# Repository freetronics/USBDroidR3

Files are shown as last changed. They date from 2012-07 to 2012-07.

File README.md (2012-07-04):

Freetronics USBDroid R3
=======================
Copyright 2011-2012 Freetronics Pty Ltd  
Freetronics site:  www.freetronics.com  
Freetronics email: info@freetronics.com  

The USBDroid is a 100% Arduino Compatible Board, based on the existing
Uno, but with improvements and updates for ease of use, cost
and getting started. It also includes on-board USB host functionality
using a dedicated port.

Features:

 * Micro-USB connector
 * Integrated USB host functionality on a dedicated USB connector
 * Overlay guide where you need it (both top and bottom)
 * D13 pin works for everything
 * RX pin biased
 * Mounting holes, power and X3 pads
 * All connections in the same place

You can view more at our product page at:

  http://www.freetronics.com/usbdroid

The "docs" folder within this repository includes a handy copy of the
schematic in PDF format, images of the pcb, and our Getting Started
guide that ships with each board.

INSTALLATION
------------
The design is saved as an EAGLE project. EAGLE PCB design software is
available from www.cadsoftusa.com free for non-commercial use. To use
this project download it and place the directory containing these files
into the "eagle" directory on your computer. Then open EAGLE and
navigate to Projects -> eagle -> USBHost.

DISTRIBUTION
------------
The specific terms of distribution of this project are governed by the
license referenced below.

LICENSE
-------
This work is licensed under the
Creative Commons Attribution-Share Alike License.  
To view a copy of this license, visit

  http://creativecommons.org/licenses/by-sa/3.0/  
  http://creativecommons.org/licenses/by-sa/3.0/legalcode

or send a letter to

  Creative Commons  
  171 Second Street, Suite 300  
  San Francisco  
  California, 94105  
  USA

The "license" folder within this repository also contains copies of the
licences referenced above.

CREDITS
-------
The USBHost was designed by Marc Alexander (marc@freetronics.com).

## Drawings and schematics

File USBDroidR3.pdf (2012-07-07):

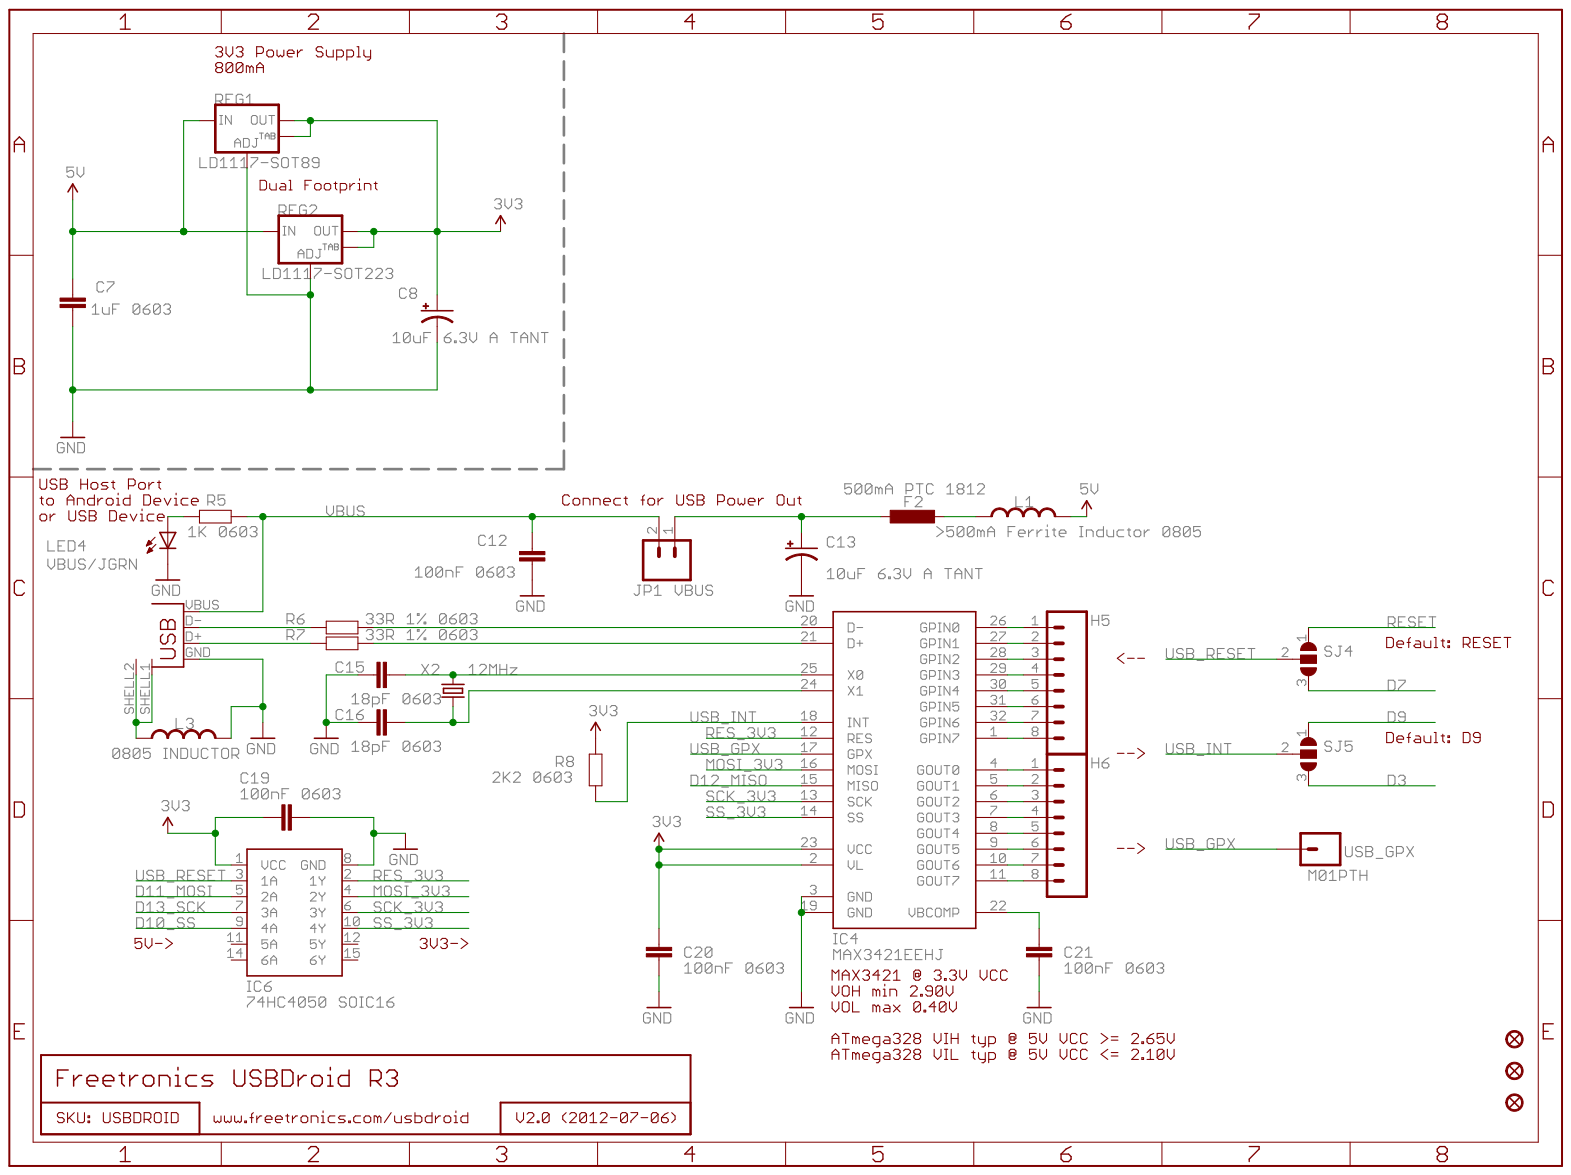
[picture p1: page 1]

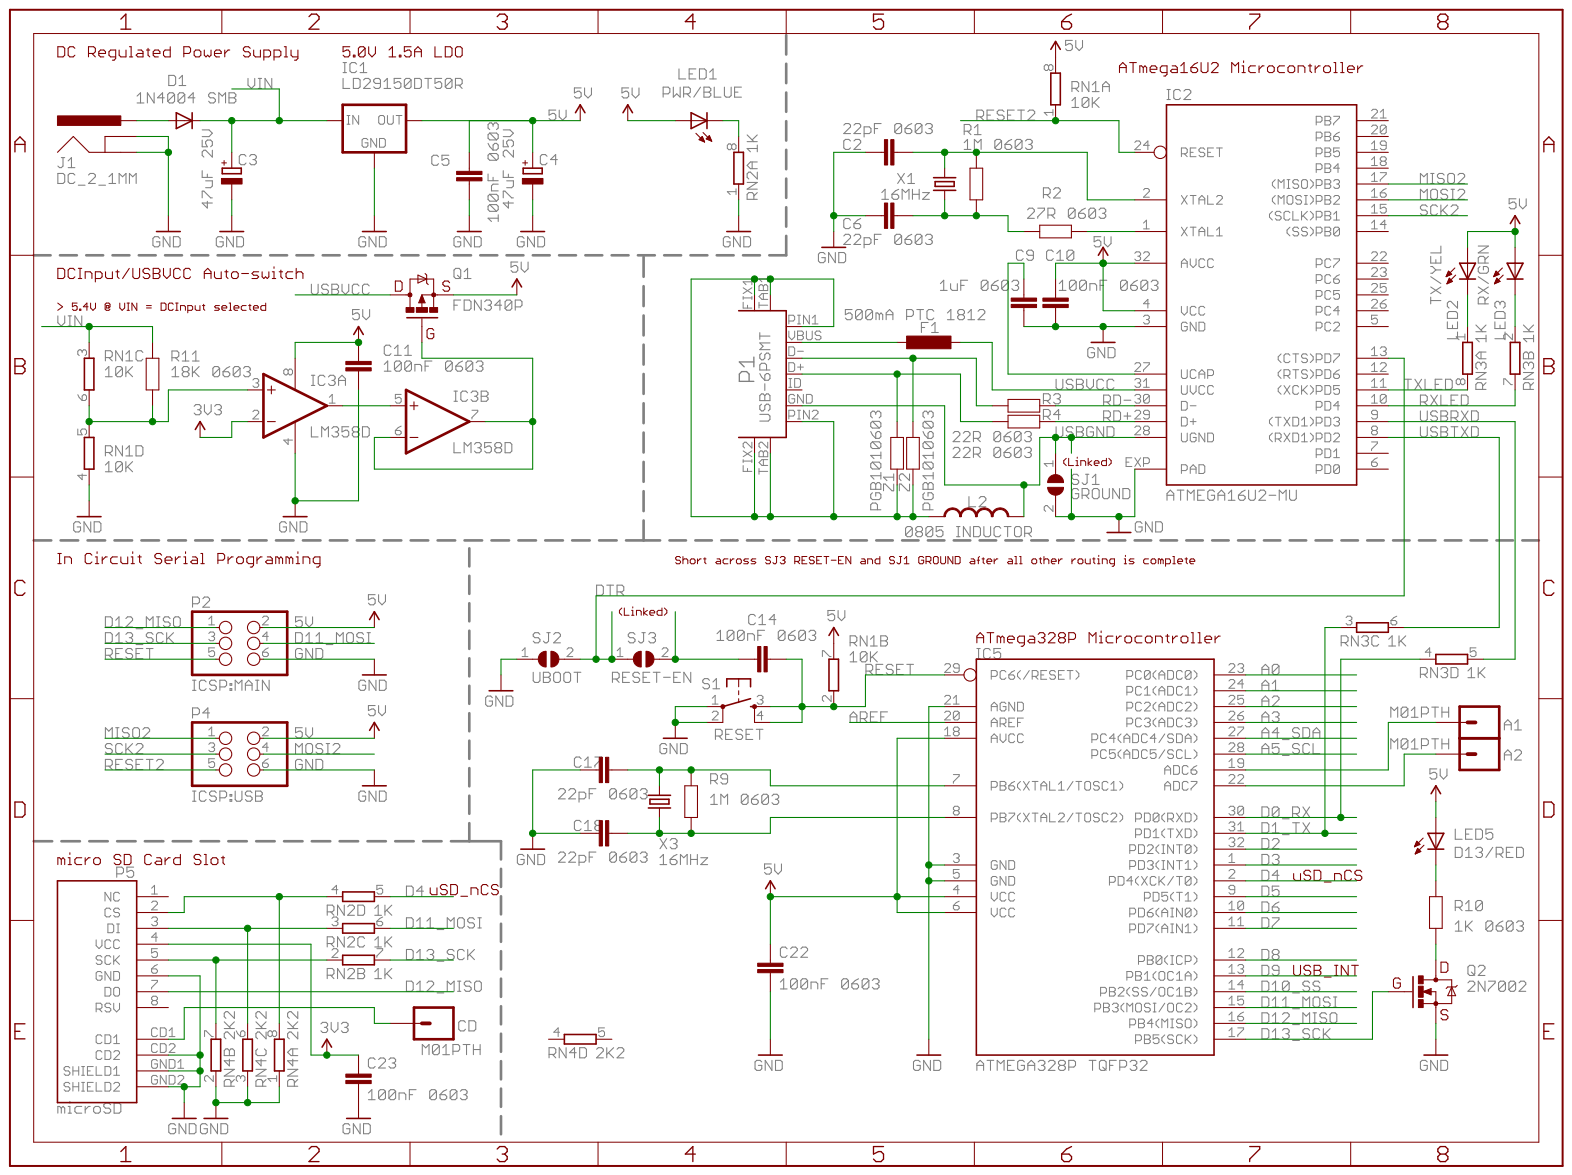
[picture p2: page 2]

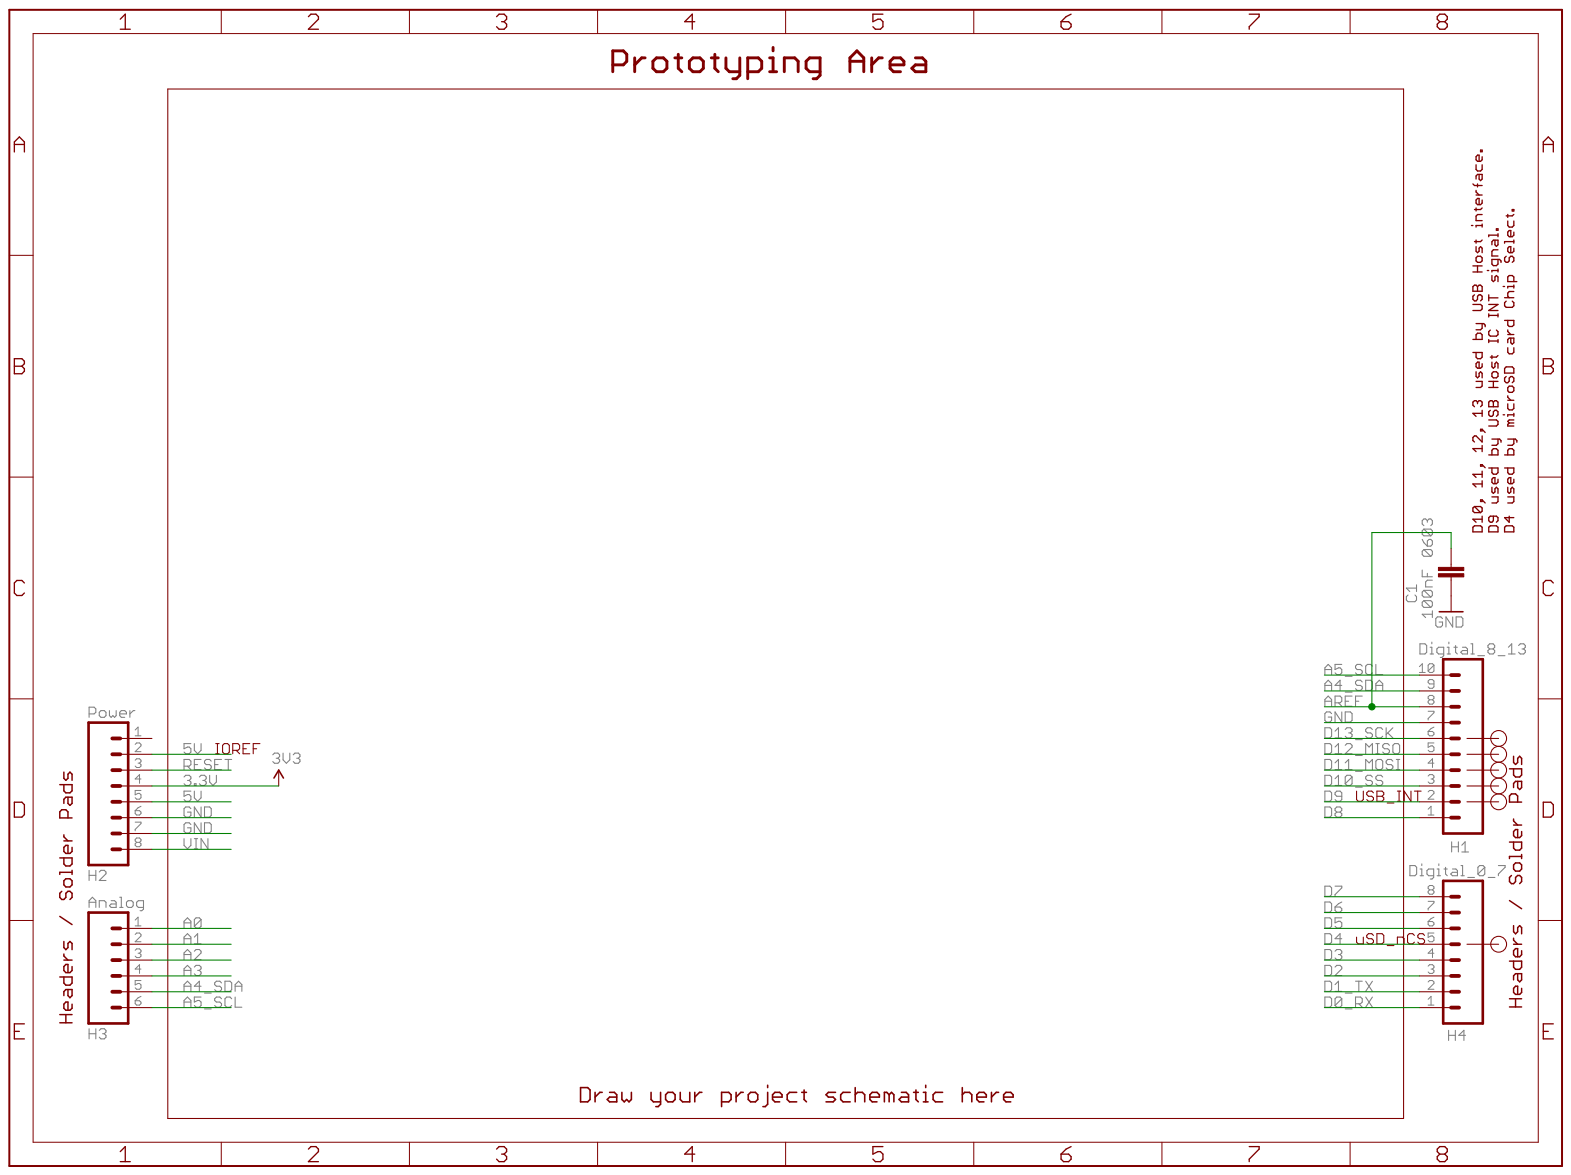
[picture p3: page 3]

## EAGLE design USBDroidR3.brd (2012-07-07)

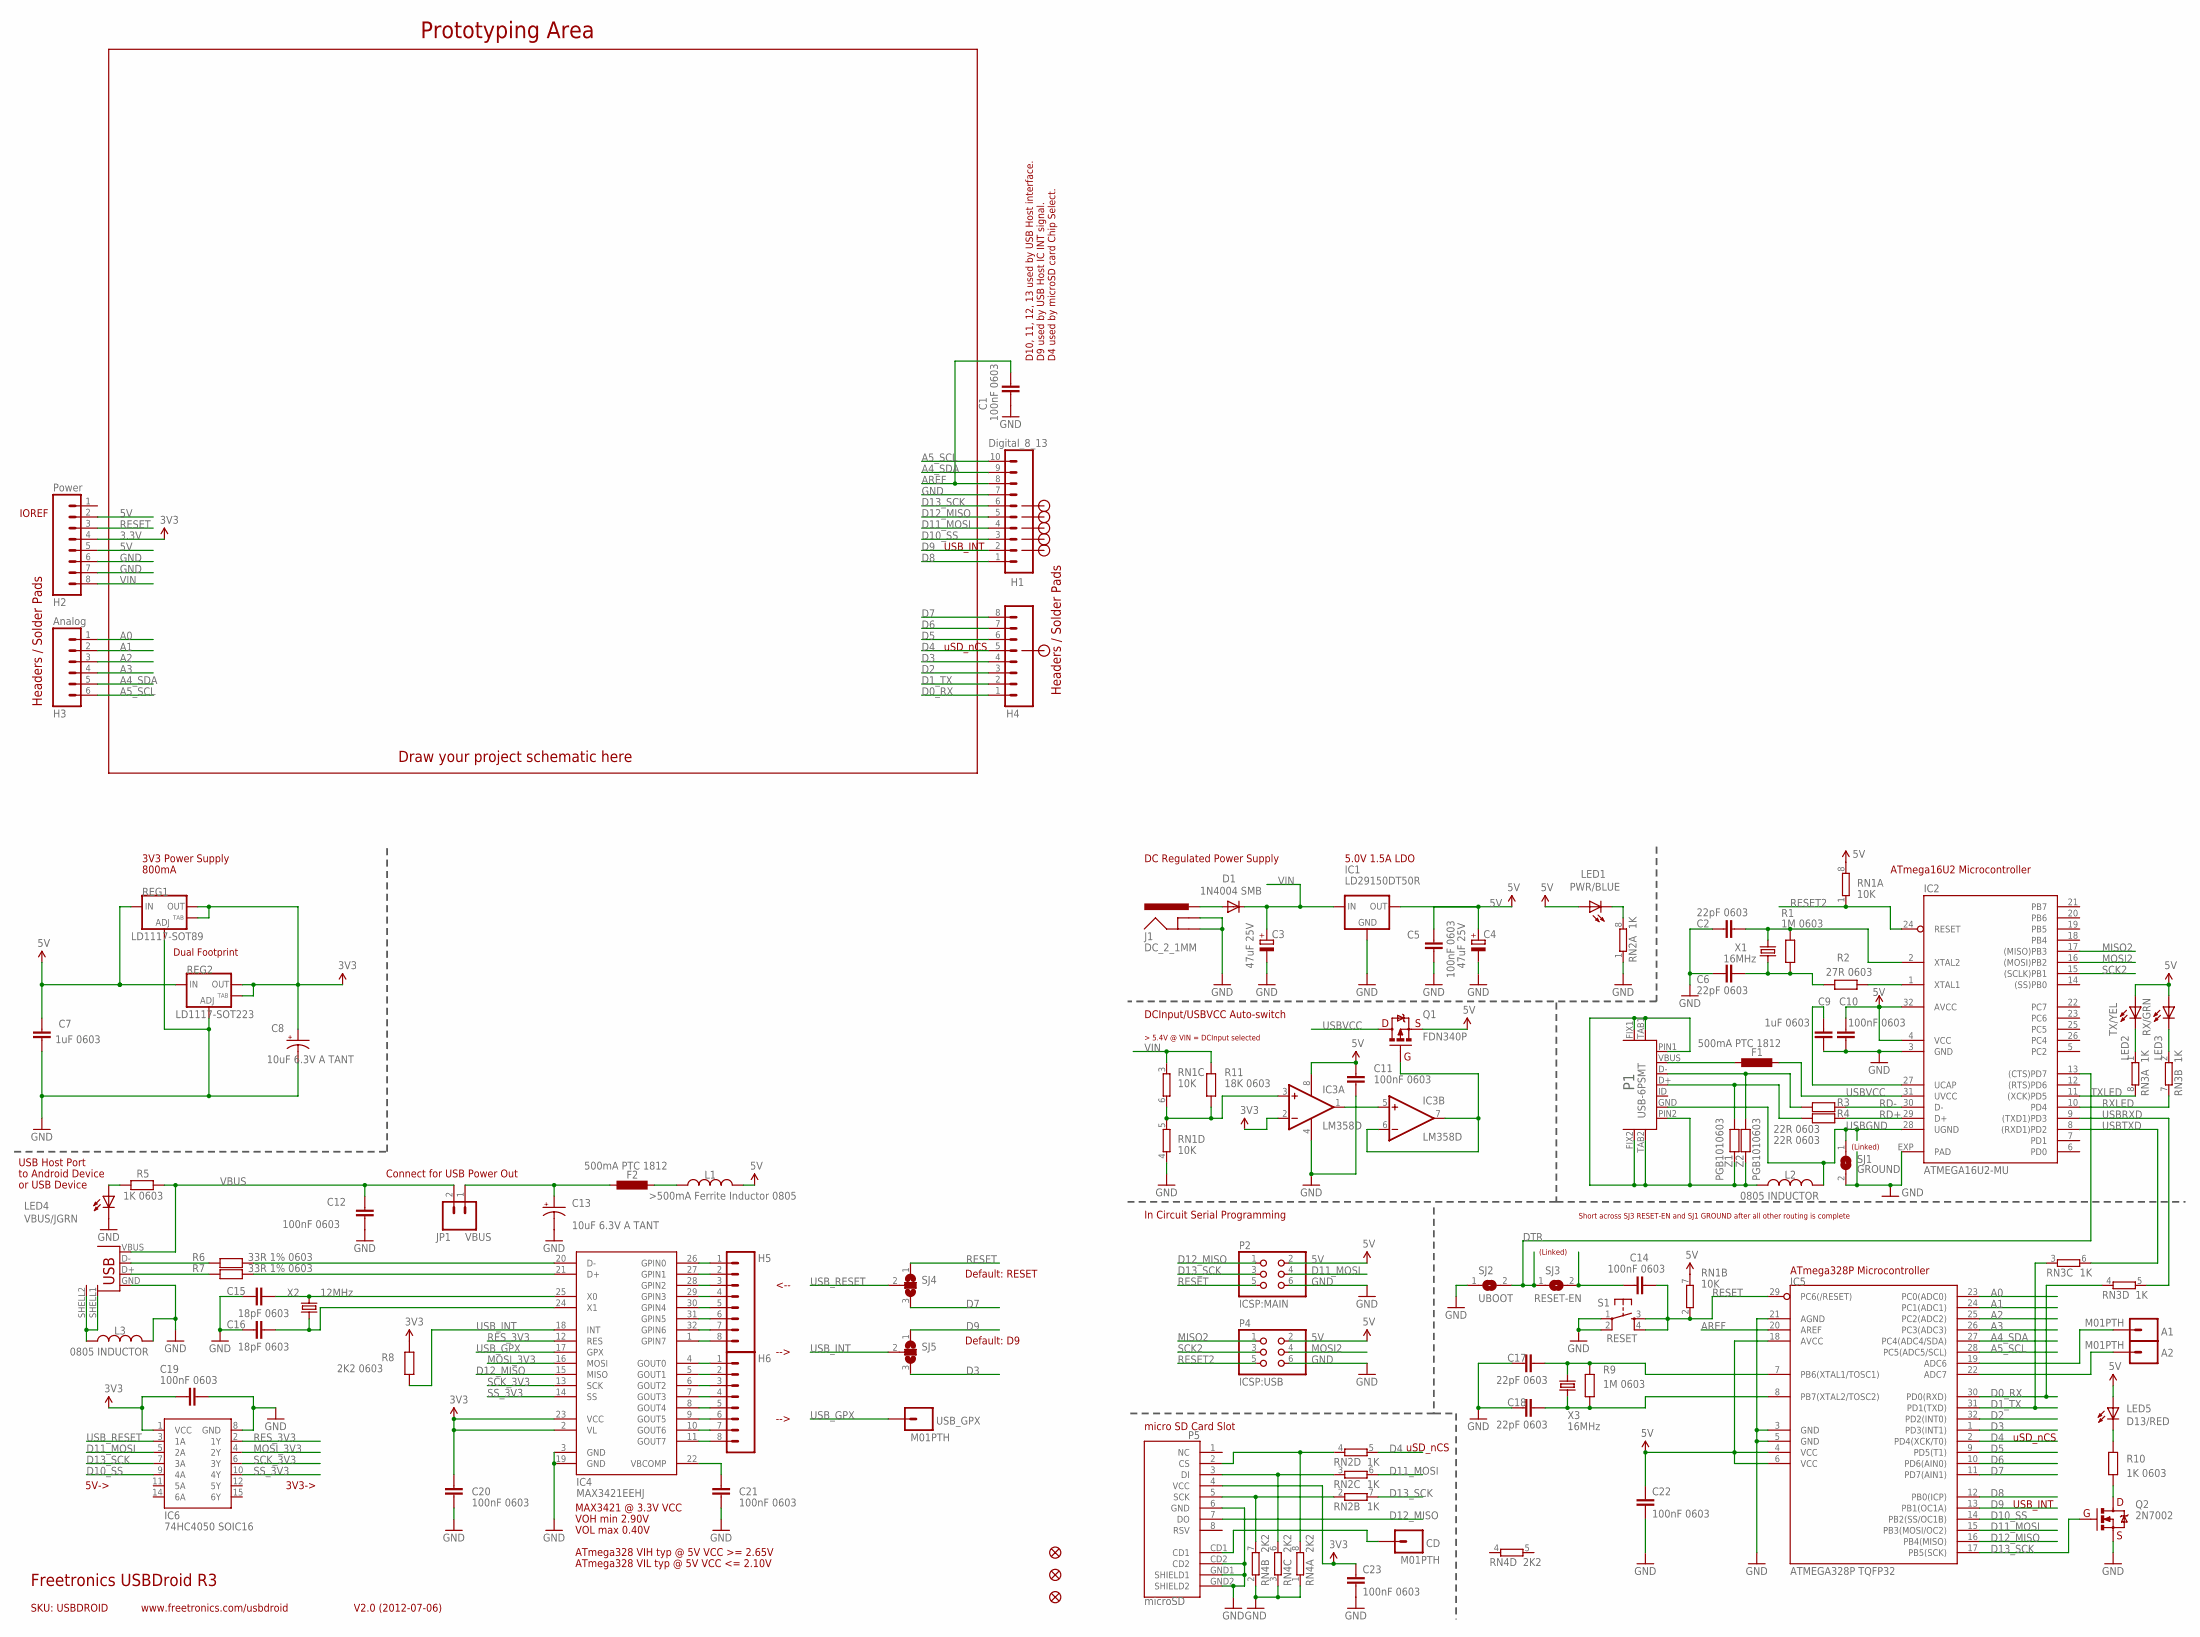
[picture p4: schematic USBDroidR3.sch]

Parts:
A1, A2: M01PTH; 1X01
C1, C5, C10, C11, C12, C14, C19, C20, C21, C22, C23: 100nF 0603; 0603
C2, C6, C17, C18: 22pF 0603; 0603
C3, C4: 47uF 25V; PANASONIC_D
C7, C9: 1uF 0603; 0603
C8, C13: 10uF 6.3V A TANT; EIA3216
C15, C16: 18pF 0603; 0603
CD: M01PTH; 1X01
D1: 1N4004 SMB; SMB-DIODE
F1, F2: 500mA PTC 1812; L1812
FID1, FID2, FID3: FIDUCIAL1X2.5; FIDUCIAL-1X2.5
H1: Digital_8_13; 1X10
H2: Power; 1X08
H3: Analog; 1X06
H4: Digital_0_7; 1X08
H5, H6: GPIN; 1X08
IC1: LD29150DT50R; DPACK
IC2: ATMEGA16U2-MU; ATMEL_QFN32
IC3: LM358D; SO08
IC4: MAX3421EEHJ; TQFP32-5MM
IC5: ATMEGA328P TQFP32; TQFP32-08
IC6: 74HC4050 SOIC16; SO016
J1: DC_2_1MM; POWER_JACK_PTH
JP1: VBUS; 1X02_LOCK
L1: >500mA Ferrite Inductor 0805; 0805-LARGE
L2, L3: 0805 INDUCTOR; 0805-LARGE
LED1: PWR/BLUE; LED-0603
LED2: TX/YEL; LED-0603
LED3: RX/GRN; LED-0603
LED4: VBUS/JGRN; LED-0603
LED5: D13/RED; LED-0603
P1: USB-6PSMT; USB-MICROB-MB05PMXX
P2: ICSP:MAIN; 2X03
P3: USB_; USB-A-S-SILK-FEMALE
P4: ICSP:USB; 2X03
P5: microSD; MICRO-SD-SOCKET-PP
Q1: FDN340P; SOT23
Q2: 2N7002; SOT23-3
R1, R9: 1M 0603; 0603
R2: 27R 0603; 0603
R3, R4: 22R 0603; 0603
R5, R10: 1K 0603; 0603
R6, R7: 33R 1% 0603; 0603
R8: 2K2 0603; 0603
R11: 18K 0603; 0603
REG1: LD1117-SOT89; SOT89
REG2: LD1117-SOT223; SOT223
RN1: 10K; CAY16
RN2, RN3: 1K; CAY16
RN4: 2K2; CAY16
S1: RESET; TACTILE_SWITCH_SMD
SJ1: GROUND; SJ
SJ2: UBOOT; SJ
SJ3: RESET-EN; SJ
SJ4, SJ5: SJ2W; SJ_2
USB_GPX: M01PTH; 1X01
X1, X3: 16MHz; HC49U-V
X2: 12MHz; HC49U-V
Z1, Z2: PGB1010603; 0603

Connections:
3.3V: C8.A (+), C19.2, C20.2, C23.1, H2.4, IC3.2 (-IN), IC4.2 (VL), IC4.23 (VCC), IC6.1 (VCC), P5.4 (VCC), R8.1, REG1.2 (OUT), REG1.4 (OUT), REG2.2 (OUT), REG2.4 (OUT)
5V: C4.+, C5.1, C7.1, C10.1, C11.1, C22.1, H2.2, H2.5, IC1.3 (OUT), IC2.4 (VCC), IC2.32 (AVCC), IC3.8 (V+), IC5.4 (VCC), IC5.6 (VCC), IC5.18 (AVCC), L1.2, LED1.A, LED2.A, LED3.A, LED5.A, P2.2, P4.2, Q1.2 (S), REG1.3 (IN), REG2.3 (IN), RN1.7 (2), RN1.8 (2)
A0: H3.1, IC5.23 (PC0(ADC0))
A1: H3.2, IC5.24 (PC1(ADC1))
A2: H3.3, IC5.25 (PC2(ADC2))
A3: H3.4, IC5.26 (PC3(ADC3))
A4_SDA: H1.9, H3.5, IC5.27 (PC4(ADC4/SDA))
A5_SCL: H1.10, H3.6, IC5.28 (PC5(ADC5/SCL))
AREF: C1.1, H1.8, IC5.20 (AREF)
D0_RX: H4.1, IC5.30 (PD0(RXD)), RN3.4 (1)
D1_TX: H4.2, IC5.31 (PD1(TXD)), RN3.3 (1)
D2: H4.3, IC5.32 (PD2(INT0))
D3: H4.4, IC5.1 (PD3(INT1)), SJ5.3
D4: H4.5, IC5.2 (PD4(XCK/T0)), RN2.5 (2)
D5: H4.6, IC5.9 (PD5(T1))
D6: H4.7, IC5.10 (PD6(AIN0))
D7: H4.8, IC5.11 (PD7(AIN1)), SJ4.3
D8: H1.1, IC5.12 (PB0(ICP))
D9: H1.2, IC5.13 (PB1(OC1A)), SJ5.1
D10_SS: H1.3, IC5.14 (PB2(SS/OC1B)), IC6.9 (4A)
D11_MOSI: H1.4, IC5.15 (PB3(MOSI/OC2)), IC6.5 (2A), P2.4, RN2.6 (2)
D12_MISO: H1.5, IC4.15 (MISO), IC5.16 (PB4(MISO)), P2.1, P5.7 (DO)
D13_SCK: H1.6, IC5.17 (PB5(SCK)), IC6.7 (3A), P2.3, Q2.1 (G), RN2.7 (2)
DTR: IC2.13 ((CTS)PD7), SJ2.2, SJ3.1
GND: C1.2, C2.1, C3.-, C4.-, C5.2, C6.1, C7.2, C8.C (-), C9.2, C10.2, C11.2, C12.1, C13.C (-), C15.1, C16.1, C17.1, C18.1, C19.1, C20.1, C21.1, C22.2, C23.2, H1.7, H2.6, H2.7, IC1.2 (GND), IC2.3 (GND), IC2.EXP (PAD), IC3.4 (V-), IC4.3 (GND), IC4.19 (GND), IC5.3 (GND), IC5.5 (GND), IC5.21 (AGND), IC6.8 (GND), J1.GND, J1.GNDBREAK, L3.2, LED4.C, P2.6, P3.GND, P4.6, P5.6 (GND), P5.CD2, P5.GND1 (SHIELD1), P5.GND2 (SHIELD2), Q2.2 (S), REG1.1 (ADJ), REG2.1 (ADJ), RN1.4 (1), RN2.1, RN4.1, RN4.2 (1), RN4.3 (1), S1.1, S1.2, SJ1.2, SJ2.1
MISO2: IC2.17 ((MISO)PB3), P4.1
MOSI2: IC2.16 ((MOSI)PB2), P4.4
MOSI_3V3: IC4.16 (MOSI), IC6.4 (2Y)
unnamed: P3.D-, R6.2
unnamed: C17.2, IC5.7 (PB6(XTAL1/TOSC1)), R9.2, X3.2
unnamed: P3.D+, R7.2
unnamed: LED5.C, R10.2
unnamed: IC4.20 (D-), R6.1
unnamed: Q2.3 (D), R10.1
unnamed: C18.2, IC5.8 (PB7(XTAL2/TOSC2)), R9.1, X3.1
unnamed: IC2.1 (XTAL1), R2.1
unnamed: IC4.21 (D+), R7.1
unnamed: LED3.C, RN3.2 (1)
unnamed: IC3.3 (+IN), R11.1, RN1.5 (2), RN1.6 (2)
unnamed: LED2.C, RN3.1
unnamed: LED1.C, RN2.8 (2)
unnamed: H5.1, IC4.26 (GPIN0)
unnamed: P1.D+, R4.2, Z1.1
unnamed: P1.D-, R3.2, Z2.1
unnamed: IC3.6 (-IN), IC3.7 (OUT), Q1.1 (G)
unnamed: IC3.1 (OUT), IC3.5 (+IN)
unnamed: P5.2 (CS), RN2.4 (1), RN4.8 (2)
unnamed: A2.1, IC5.22 (ADC7)
unnamed: A1.1, IC5.19 (ADC6)
unnamed: CD.1, P5.CD1
unnamed: P5.5 (SCK), RN2.2 (1), RN4.7 (2)
unnamed: P5.3 (DI), RN2.3 (1), RN4.6 (2)
unnamed: H5.2, IC4.27 (GPIN1)
unnamed: C15.2, IC4.25 (X0), X2.2
unnamed: H5.3, IC4.28 (GPIN2)
unnamed: C13.A (+), F2.1, JP1.1
unnamed: C16.2, IC4.24 (X1), X2.1
unnamed: H5.4, IC4.29 (GPIN3)
unnamed: H5.5, IC4.30 (GPIN4)
unnamed: H5.6, IC4.31 (GPIN5)
unnamed: H5.7, IC4.32 (GPIN6)
unnamed: H5.8, IC4.1 (GPIN7)
unnamed: H6.1, IC4.4 (GOUT0)
unnamed: H6.2, IC4.5 (GOUT1)
unnamed: H6.3, IC4.6 (GOUT2)
unnamed: H6.4, IC4.7 (GOUT3)
unnamed: H6.5, IC4.8 (GOUT4)
unnamed: H6.6, IC4.9 (GOUT5)
unnamed: H6.7, IC4.10 (GOUT6)
unnamed: H6.8, IC4.11 (GOUT7)
unnamed: LED4.A, R5.1
unnamed: L3.1, P3.SHELL1, P3.SHELL2
unnamed: F2.2, L1.1
unnamed: C21.2, IC4.22 (VBCOMP)
unnamed: C14.1, SJ3.2
unnamed: L2.1, P1.FIX1, P1.FIX2, P1.PIN1, P1.PIN2, P1.TAB1, P1.TAB2, Z1.2, Z2.2
unnamed: D1.A, J1.PWR
unnamed: C2.2, IC2.2 (XTAL2), R1.2, X1.2
unnamed: C6.2, R1.1, R2.2, X1.1
unnamed: F1.1, P1.VBUS
unnamed: C9.1, IC2.27 (UCAP)
RD+: IC2.29 (D+), R4.1
RD-: IC2.30 (D-), R3.1
RESET: C14.2, H2.3, IC5.29 (PC6(/RESET)), P2.5, RN1.2 (1), S1.3, S1.4, SJ4.1
RESET2: IC2.24 (RESET), P4.5, RN1.1
RES_3V3: IC4.12 (RES), IC6.2 (1Y)
RXLED: IC2.10 (PD4), RN3.7 (2)
SCK2: IC2.15 ((SCLK)PB1), P4.3
SCK_3V3: IC4.13 (SCK), IC6.6 (3Y)
SS_3V3: IC4.14 (SS), IC6.10 (4Y)
TXLED: IC2.11 ((XCK)PD5), RN3.8 (2)
USBGND: IC2.28 (UGND), L2.2, P1.GND, SJ1.1
USBRXD: IC2.9 ((TXD1)PD3), RN3.5 (2)
USBTXD: IC2.8 ((RXD1)PD2), RN3.6 (2)
USBVCC: F1.2, IC2.31 (UVCC), Q1.3 (D)
USB_GPX: IC4.17 (GPX), USB_GPX.1
USB_INT: IC4.18 (INT), R8.2, SJ5.2
USB_RESET: IC6.3 (1A), SJ4.2
VBUS: C12.2, JP1.2, P3.VBUS, R5.2
VIN: C3.+, D1.C, H2.8, IC1.1 (IN), R11.2, RN1.3 (1)

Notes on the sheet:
Prototyping Area
SKU: USBDROID
3V3 Power Supply
Headers / Solder Pads
Dual Footprint
Draw your project schematic here
D10, 11, 12, 13 used by USB Host interface.
D9 used by USB Host IC INT signal.
DC Regulated Power Supply
ATmega328P Microcontroller
ATmega16U2 Microcontroller
DCInput/USBVCC Auto-switch
uSD_nCS
800mA
In Circuit Serial Programming
micro SD Card Slot
Freetronics USBDroid R3
V2.0 (2012-07-06)
www.freetronics.com/usbdroid
D4 used by microSD card Chip Select.
5.0V 1.5A LDO
5V->
3V3->
USB Host Port
to Android Device
or USB Device
Connect for USB Power Out
VOH min 2.90V
VOL max 0.40V
ATmega328 VIH typ @ 5V VCC >= 2.65V
MAX3421 @ 3.3V VCC
ATmega328 VIL typ @ 5V VCC <= 2.10V
<--
Default: RESET
Default: D9
-->
USB_INT
IOREF
(Linked)
Short across SJ3 RESET-EN and SJ1 GROUND after all other routing is complete

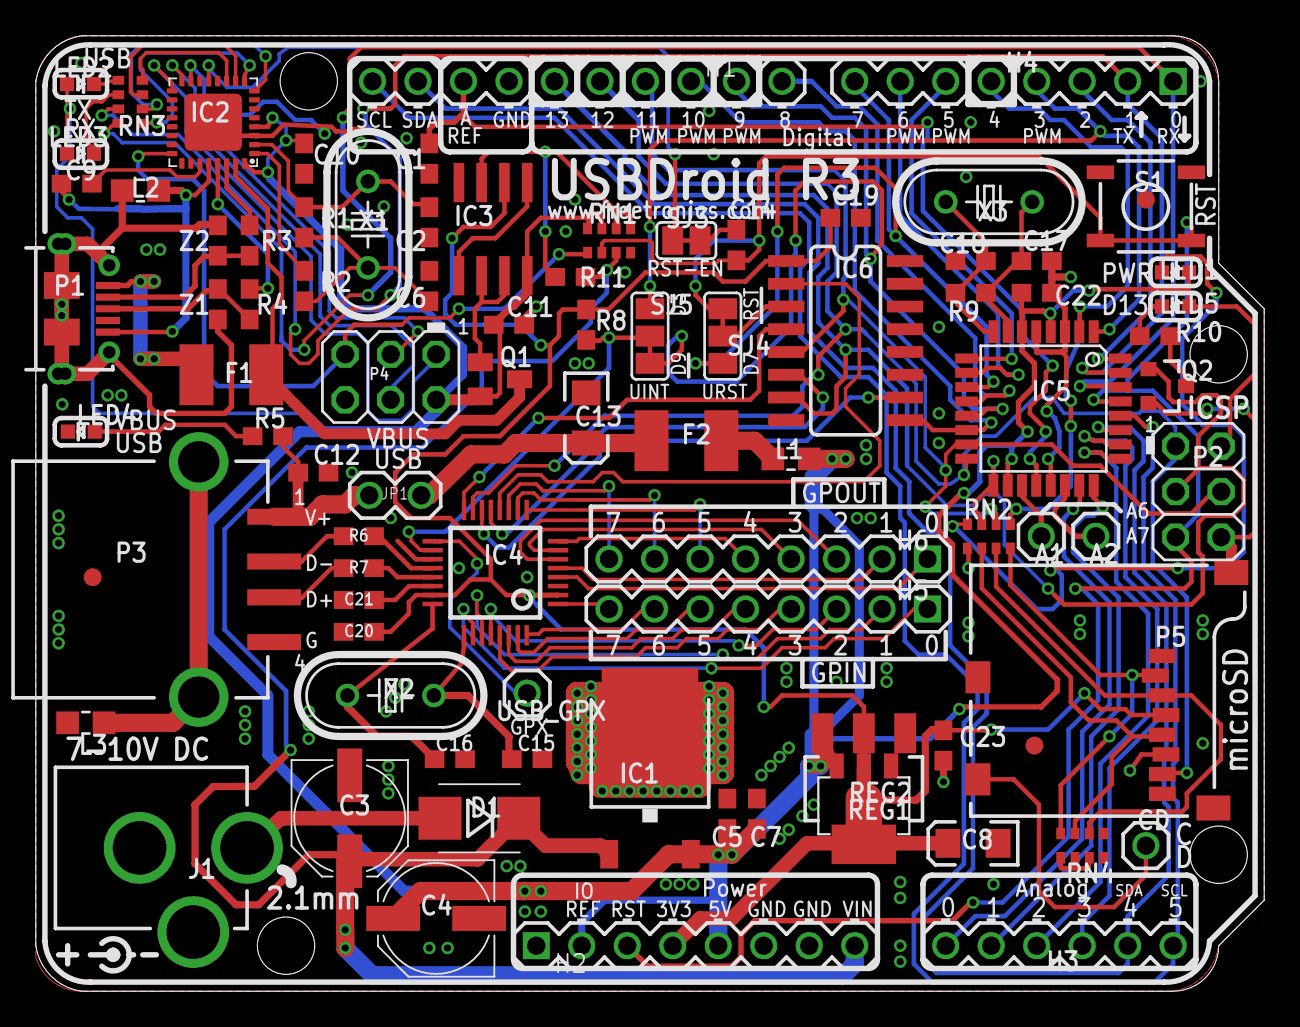
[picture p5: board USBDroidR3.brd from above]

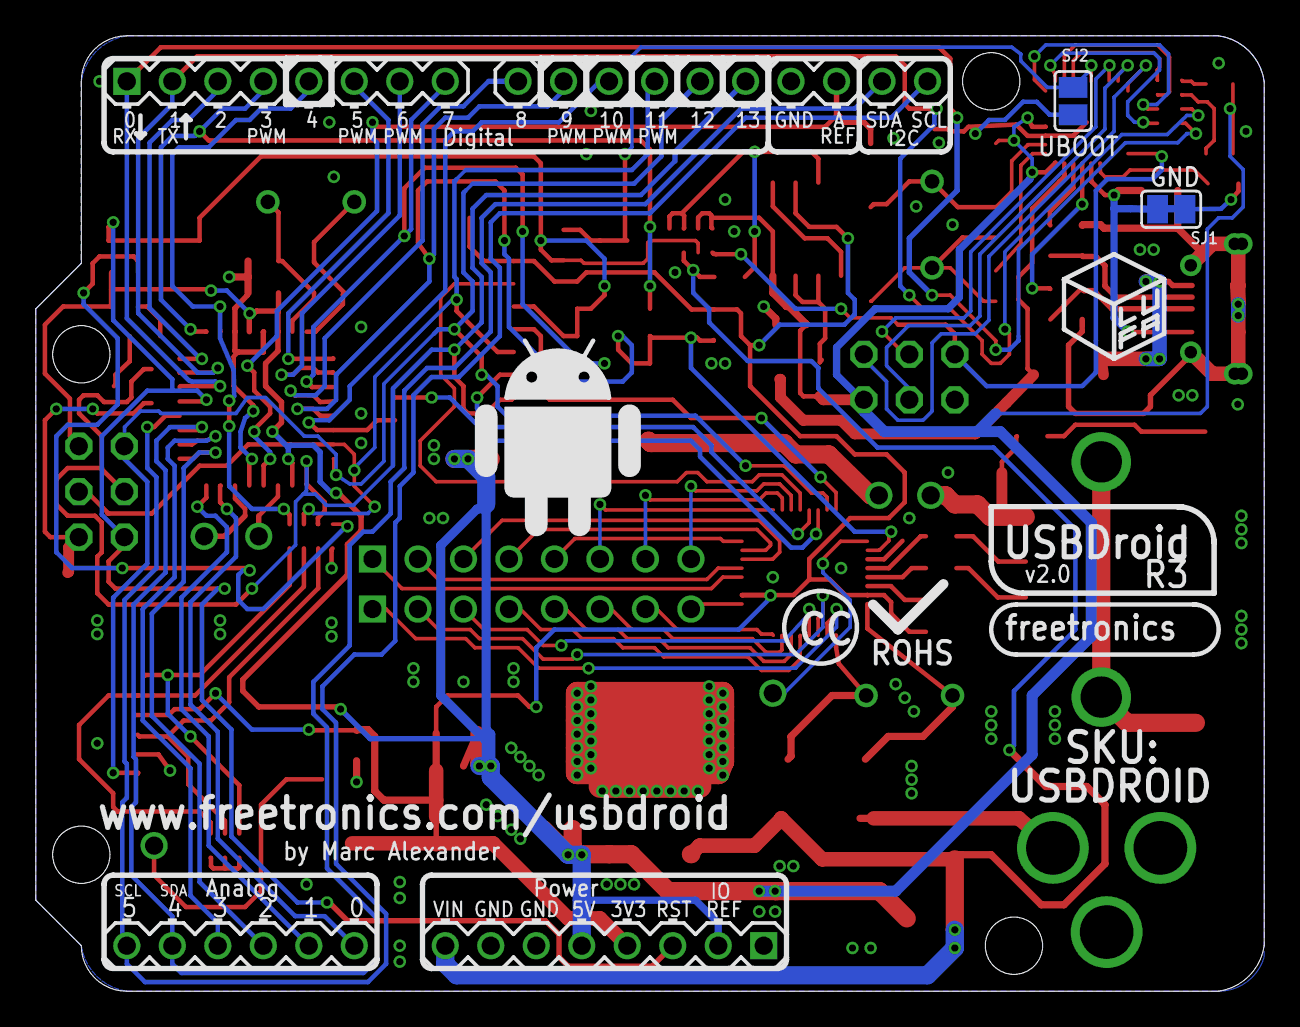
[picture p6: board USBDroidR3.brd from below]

Board: 2 copper layers, 68.6 x 53.3 mm, 90 parts (2 on the bottom side), 100 nets.

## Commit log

2012-07-04 Renamed project files for R3 fork
    [USBDroidR3.brd, USBDroidR3.sch]
2012-07-04 R3 headers, microUSB, 16u2
    [USBDroidR3.brd, USBDroidR3.sch]
2012-07-06 R3 updates
    [USBDroidR3.brd, USBDroidR3.sch]
2012-07-07 Updated designators, ERC and DRC for release
    [USBDroidR3.brd, USBDroidR3.sch]
2012-07-07 R3 v2.0 production files released
    [USBDroidR3.sch]

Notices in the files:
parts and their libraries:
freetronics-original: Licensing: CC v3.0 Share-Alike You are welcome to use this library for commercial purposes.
